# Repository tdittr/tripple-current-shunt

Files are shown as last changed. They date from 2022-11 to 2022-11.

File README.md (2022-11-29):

# Tripple Current Shunt

This is a small PCB project to measure current consumption and voltages in a multi battery camper van environment.

To do this it hosts three [INA219](https://www.ti.com/product/INA219) power monitors,
one [ADS1015](https://www.ti.com/product/ADS1015) four channel ADC to measure ground offsets,
one [MCP9808](https://www.microchip.com/en-us/product/MCP9808) temperature sensor and
a [M24C02](https://www.st.com/en/memories/m24c02-r.html) EEPROM to store calibration data.

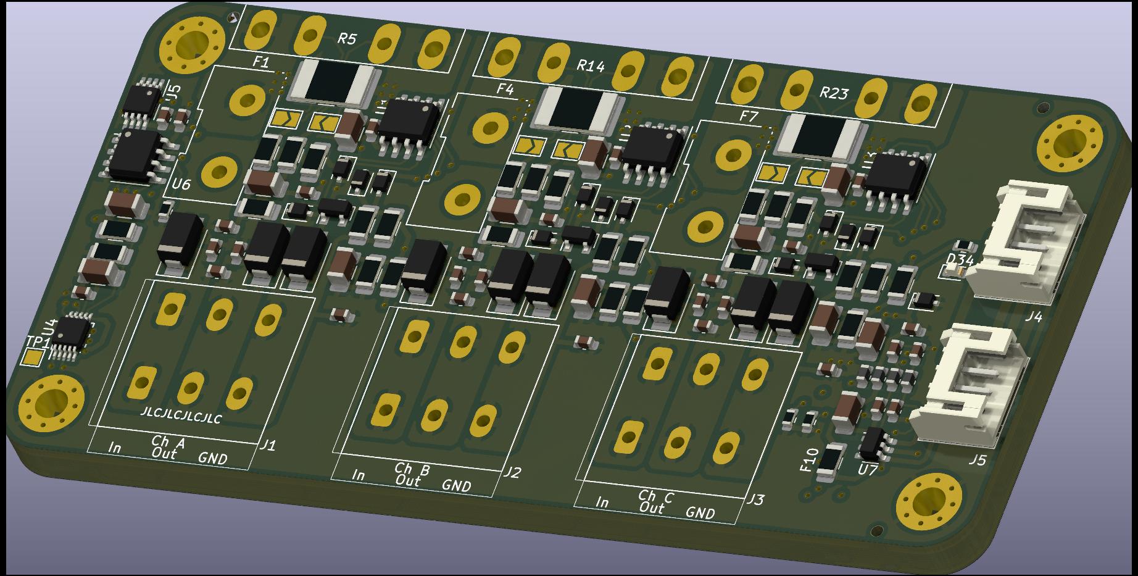
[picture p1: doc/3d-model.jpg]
3D Model of the board


## Interfaces

The board has three different interfaces. A [I2C](#i2c) digital interface for reading the measurements.
Three [Current Inputs](#current-input)
to measure the current flows into and out of the batteries. Three [Voltage Inputs](#voltage-input) to measure the ground
offset of the batteries.

### I2C

The I2C interface is wired to two JST-PH connectors with a pin-out compatible
to [Adafruits Stemma](https://learn.adafruit.com/introducing-adafruit-stemma-qt/technical-specs) connection. The
footprint also fits the connector and pin-out
of [Seedstudios Grove System](https://wiki.seeedstudio.com/Grove_System/#grove-i2c). The two connectors are wired in
parallel to allow for daisy-chaining. The power is also supplied via this connector (from rev2 onwards).

**Note on using Grove Connectors:** The 90 degree version of the grove connector seem to count their pins from right to
left - so inverse to how JST counts their pins. To use the Grove connectors you can either mount them on the backside of
the board or use the upright connectors with the clip facing to the edge of the board.

#### I2C Addresses

The six I2C slaves on the board are configured to follow a schema where the lowest two bits of the address are defined
per board. This allows usage of up to four boards with a total of 12 channels on a single bus. The individual addresses
are listed below. *xx* marks the bits set via jumpers (see screenshot below).

| Device | Address Pattern | Board 0 | Board 1 | Board 2 | Board 3 |
|---|---|---|---|---|---|
| MCP9808 | 0b001_10*xx* | 0x18 | 0x19 | 0x1a | 0x1b |
| INA219 Ch A | 0b100_00*xx* | 0x40 | 0x41 | 0x42 | 0x43 |
| INA219 Ch B | 0b100_01*xx* | 0x44 | 0x45 | 0x46 | 0x47 |
| ADS1015 | 0b100_10*xx* | 0x48 | 0x49 | 0x4a | 0x4b |
| INA219 Ch C | 0b100_11*xx* | 0x4c | 0x4d | 0x4e | 0x4f |
| M24C02 | 0b101_00*xx* | 0x50 | 0x51 | 0x52 | 0x53 |

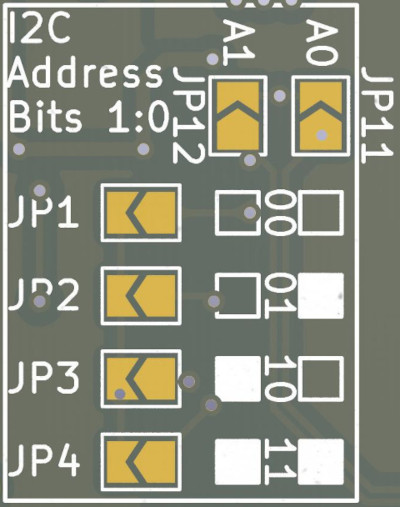
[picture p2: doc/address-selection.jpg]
Address selection jumpers screenshot
|                                                                                                                                      |
|--------------------------------------------------------------------------------------------------------------------------------------------------------------------------------------------------------|
| There should always be one of JP1, JP2, JP3 or JP4 closed. Then close JP11 or JP12 when the matching box is filled. To select for example the address *10* for the board you would close JP3 and JP12. |

### Current Input

The current inputs are connected inline between the batteries and the consumers. They can be connected using
either [Wago 2604-1103 terminal blocks](https://www.wago.com/global/pcb-terminal-blocks-and-pluggable-connectors/pcb-terminal-block/p/2604-1103)
or a single row terminal block with 5mm pin spacing.

The board offers the option to place a [miniOTO fuse holder](https://imaxx.nl/product/minioto-holder-h7810/) in line to
protect the board and connections.

The current is then converted to a voltage using a current shunt. The different options for this are described
in ["Choosing a Shunt Resistor"](#choosing-a-shunt-resistor).

### Voltage Input

To measure the voltage offset between the board ground and the battery ground the connector used for
the [Current Input](#current-input) offers an extra connection. The input can tolerate a maximum voltage of ±20V but can
only measure about a ±5V offset. This can easily be adapted to other needs,
see [Adapting Voltage Dividers](#adapting-voltage-dividers).

## Design considerations

The board is designed to be easily adaptable to different situations. The easiest adaptions are to just leave parts out:

* Remove the fuse holders (e.g. because you already have a fuse box), and bridge that footprint
* Remove the temperature sensor and/or EEPROM to save cost
* Remove the EMI filter by not populating the capacitors and bridging the ferrite-beads

For the more complex considerations see below:

### Choosing a Shunt Resistor

**1. Choosing a footprint:** The board offers four different footprints for the shunt resistors:

* Single-Inline 4-pin through-hole
  for [Isabellenhütte PBV](https://www.isabellenhuette.de/fileadmin/user_upload/PBV.PDF) resistors
* SMD 2512 resistors
* SMD 1206 resistors
* Off-Board Shunt like [Vishay RTOP](https://www.vishay.com/product/50045/)

When using any other resistor footprint then the Single-Inline one the two jumpers next to the resistor footprints needs
to be closed. This connects the voltage sense terminals to the current terminals.

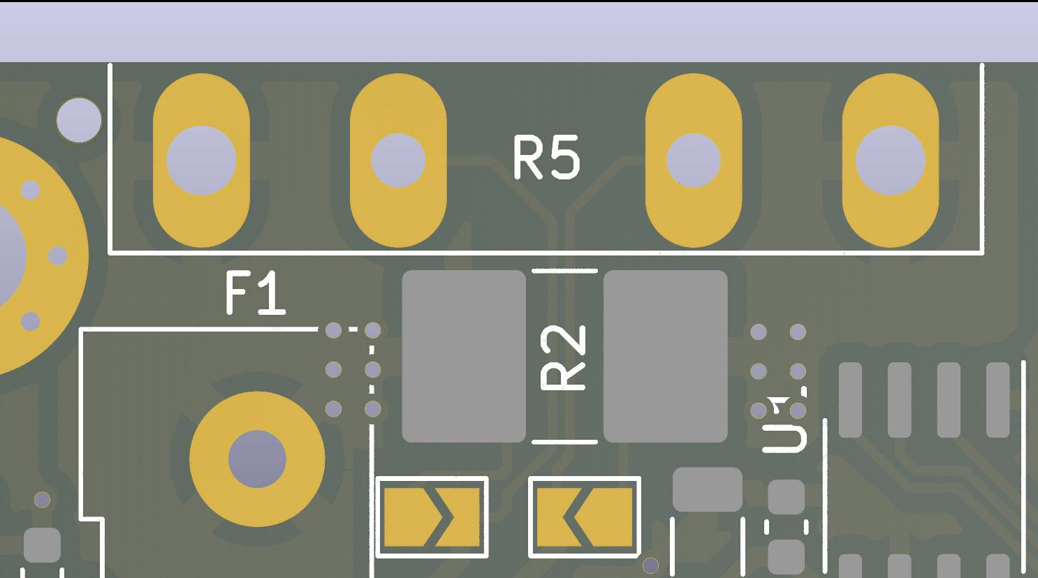
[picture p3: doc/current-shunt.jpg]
Shunt resistor footprints and jumpers


The screenshot shows the resistor footprints for channel A. R5 is for the *Single-Inline 4-pin through-hole* and R2 for
either SMD 2512 or SMD 1206. To use an external shunt do not populate any of the two. If you want to use any shunt that
is not the Single-Inline 4-pin close the two jumpers below R2.

**2. Check maximum values:** Calculate the maximum resistor value for a given current and power rating:

$R \leq \frac{P}{I^2}$

**3. Check voltage over shunt:** The INA219 can work with up to 26V but can measure a either ±40mV, ±80mV, ±160mV or
±320mV of shunt voltage. Using a lower shunt voltage will give a lower power loss on the shunt while aiming for a higher
shunt voltage increases signal-to-noise ratio.
You can calculate the voltage over the shunt by $U_{shunt}=R_{shunt} \cdot I$.

**Note:** Check whether the trace width is sufficient for your current. You can add extra solder and copper to the
traces on the bottom side to improve the current capabilities.

### Adapting Voltage Dividers

The voltage dividers for the ground offset are set to allow for ±5V input. This is achieved by building a voltage
divider between the input voltage and 5V. The output voltage can then be calculated by:

$U_{out} = \frac{5V + U_{in}}{2}$

There are however footprints to form a voltage divider between the input and ground. So it could be used to measure
another bus voltage.

**Note:** When adapting this take care to not overload the clamping diodes or the resistors in the voltage divider.

### Adapting Low Pass Filters

The current and voltage inputs host capacitors to form RC low-pass filters. The calculations for these can be found in
the schematic.

# License

Licensed under the CERN Open Hardware Licence Version 2 - Permissive.
Unless you explicitly state otherwise, any contribution intentionally submitted by you, shall be licensed as above,
without any additional terms or conditions.

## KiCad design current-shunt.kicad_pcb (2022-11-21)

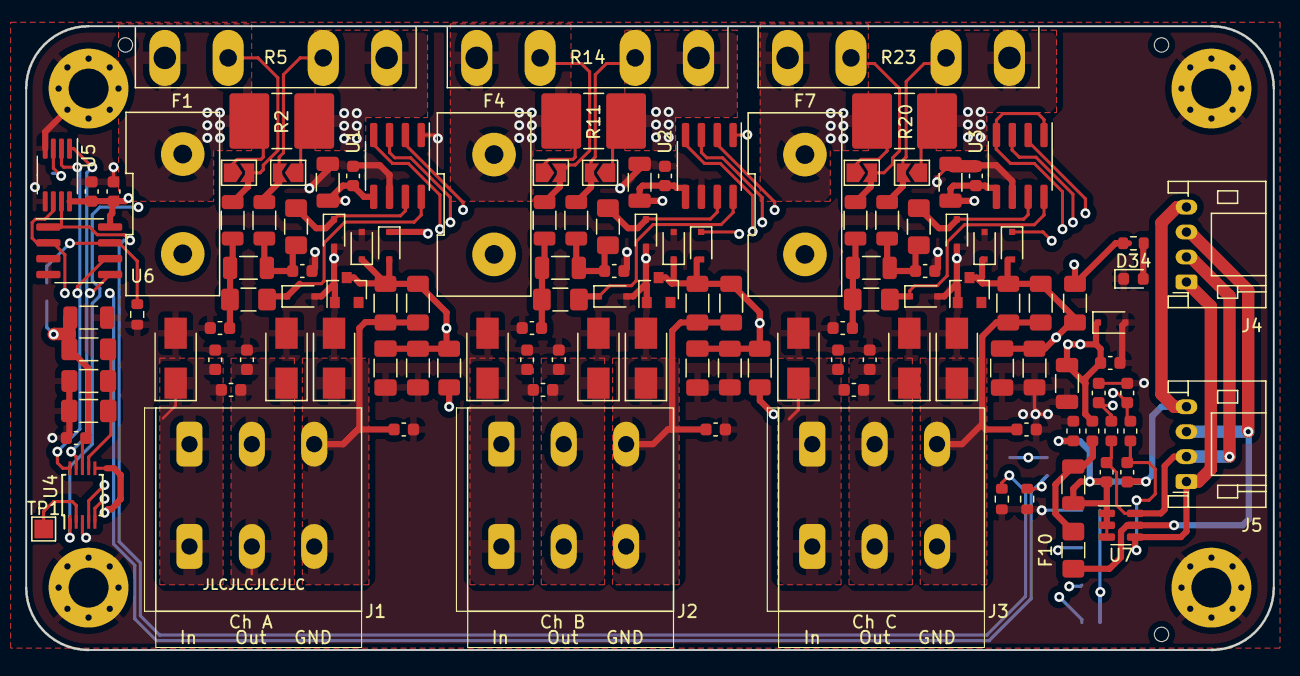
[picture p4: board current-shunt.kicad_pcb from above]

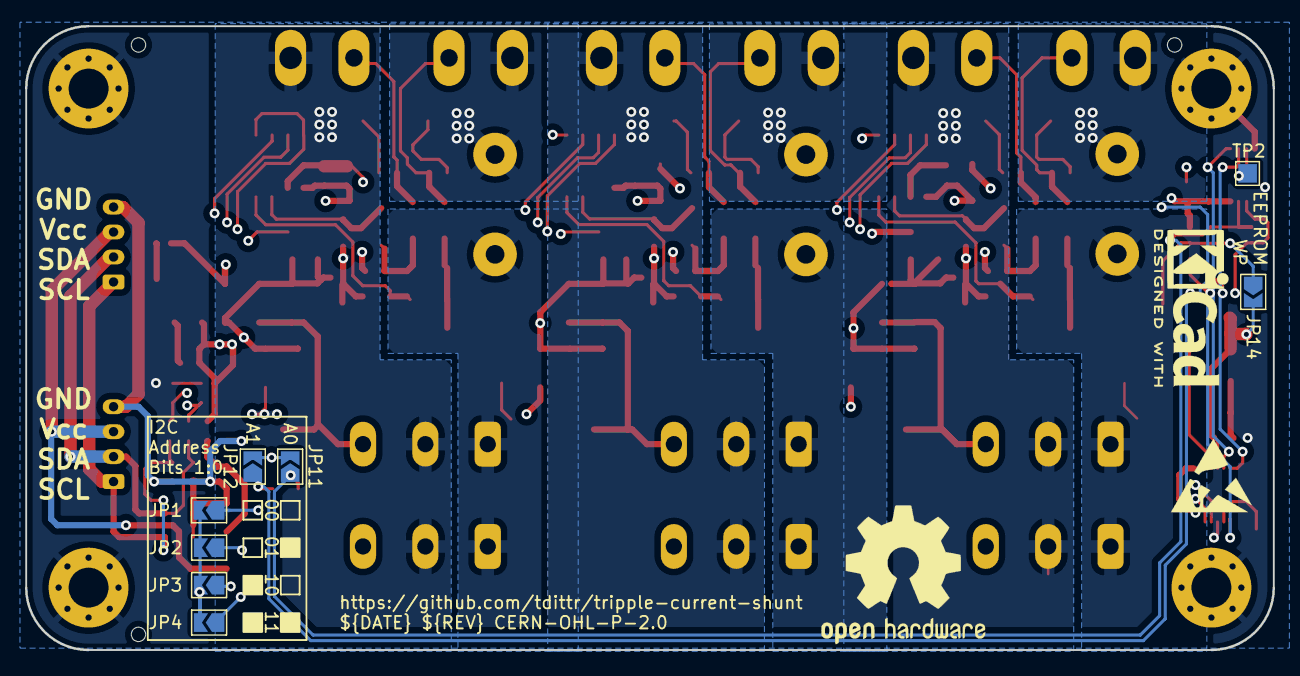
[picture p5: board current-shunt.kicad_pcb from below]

Board: 4 copper layers, 100.0 x 50.0 mm, 146 parts (11 on the bottom side), 50 nets.

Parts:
C1, C11, C21, C32, C37, C40: 10uF; C_1206_3216Metric
C2, C9, C10, C12, C19, C20, C22, C29, C30, C33, C34, C35, C36: 100nF; C_0603_1608Metric
C3, C4, C5, C6, C13, C14, C15, C16, C23, C24, C25, C26: 10nF; C_0603_1608Metric
C7, C17, C27, C31: 330nF; C_1206_3216Metric_Pad1.33x1.80mm_HandSolder
C8, C18, C28: 1uF; C_1206_3216Metric
C38, C39, C41, C42: 33pF; C_0603_1608Metric
D4, D5, D6, D15, D16, D17, D26, D27, D28: SMAJ20CA; D_SMA
D7, D8, D9, D10, D18, D19, D20, D21, D29, D30, D31, D32, D35: PMEG4010BEA; D_SOD-323F
D11, D22, D33: BZX84C 4V7; D_SOT-23_ANK
D34: LED; LED_0603_1608Metric
F1, F4, F7: Fuse; iMaXX-H7810
F2, F3, F5, F6, F8, F9, F10: 1206L016WR; Fuse_1206_3216Metric_Pad1.42x1.75mm_HandSolder
FB1, FB2, FB3, FB4: FerriteBead; L_0603_1608Metric
H1, H2, H3, H4: MountingHole_Pad; MountingHole_3.2mm_M3_Pad_Via
J1, J2, J3: Screw_Terminal_01x03; Wago_2604-1103
J4, J5: Conn_01x04; JST_PH_S4B-PH-K_1x04_P2.00mm_Horizontal
JP1, JP2, JP3, JP4, JP5, JP6, JP7, JP8, JP9, JP10, JP11, JP12, JP14: SolderJumper_2_Open; SolderJumper-2_P1.3mm_Open_TrianglePad1.0x1.5mm
LOGO1: Logo_Open_Hardware_Small; OSHW-Logo2_14.6x12mm_SilkScreen
LOGO2: SYM_ESD_Small; ESD-Logo_6.6x6mm_SilkScreen
LOGO3: SYM_Arrow45_XLarge; KiCad-Logo2_5mm_SilkScreen
R2, R11, R20: R; R_2816_7142Metric_Pad3.20x4.45mm_HandSolder
R3, R4, R12, R13, R21, R22: 2k; R_1206_3216Metric_Pad1.30x1.75mm_HandSolder
R5, R14, R23: R_Shunt; R_Shunt_Isabellenhuette_PBV
R6, R7, R15, R16, R24, R25: 10R; R_1206_3216Metric
R8, R17, R26, R28, R29: 1k; R_1206_3216Metric_Pad1.30x1.75mm_HandSolder
R9, R18, R27: DNP; R_1206_3216Metric_Pad1.30x1.75mm_HandSolder
R30, R31, R33: 10K; R_0603_1608Metric
R34: 1K5; R_0603_1608Metric
TP1, TP2: TestPoint; TestPoint_Pad_1.5x1.5mm
U1, U2, U3: INA219AxD; SOIC-8_3.9x4.9mm_P1.27mm
U4: ADS1015IDGS; TSSOP-10_3x3mm_P0.5mm
U5: MCP9804_MSOP; MSOP-8_3x3mm_P0.65mm
U6: M24C02-WMN; SOIC-8_3.9x4.9mm_P1.27mm
U7: SRV05-4; SOT-23-6

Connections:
+5V: C1.1, C2.1, C11.1, C12.1, C21.1, C22.1, C32.1, C33.1, C34.1, C35.1, C36.1, C37.1, D7.1 (K), D18.1 (K), D29.1 (K), D35.1 (K), FB1.1, JP2.1 (A), JP11.2 (B), JP12.2 (B), JP14.2 (B), R8.1, R17.1, R26.1, R28.1, R34.1, U1.5 (VS), U2.1 (A1), U2.5 (VS), U3.5 (VS), U4.8 (VDD), U5.8 (VDD), U6.8 (VCC)
/SCL: C39.1, FB3.1, JP4.1 (A), U1.4 (SCL), U2.4 (SCL), U3.1 (A1), U3.4 (SCL), U4.10 (SCL), U5.2 (SCL), U6.6 (SCL)
/SDA: C38.1, FB2.1, JP3.1 (A), U1.3 (SDA), U2.3 (SDA), U3.3 (SDA), U4.9 (SDA), U5.1 (SDA), U6.5 (SDA)
/gnd-level/A0: JP1.2 (B), JP2.2 (B), JP3.2 (B), JP4.2 (B), U1.2 (A0), U2.2 (A0), U3.2 (A0), U4.1 (ADDR)
/gnd-level/ALERT: TP1.1, U4.2 (ALERT/RDY)
/gnd-level/GND-A: C7.1, D7.2 (A), D8.1 (K), D11.1 (K), R3.1, R4.1, R8.2, R9.1, U4.4 (AIN0)
/gnd-level/GND-B: C17.1, D18.2 (A), D19.1 (K), D22.1 (K), R12.1, R13.1, R17.2, R18.1, U4.5 (AIN1)
/gnd-level/GND-C: C27.1, D29.2 (A), D30.1 (K), D33.1 (K), R21.1, R22.1, R26.2, R27.1, U4.6 (AIN2)
/i2c-interface/GND_e: C40.2, C41.2, C42.2, FB4.2, J4.4, J5.4, U7.1 (IO1), U7.2 (VN), U7.3 (IO2)
/i2c-interface/SCL_e: C42.1, FB3.2, J4.1, J5.1, U7.4 (IO3)
/i2c-interface/SDA_e: C41.1, FB2.2, J4.2, J5.2, U7.6 (IO4)
/i2c-interface/Vcc_e: F10.2, J4.3, J5.3, U7.5 (VP)
/shunt-a/IN+: C3.1, C4.1, D5.1 (A1), F1.1, J1.1
/shunt-a/IN+F: F1.2, JP5.1 (A), R2.1, R5.1
/shunt-a/IN-: C4.2, C5.1, D6.1 (A1), J1.2, JP6.1 (A), R2.2, R5.4
/shunt-a/IN-GND: C6.1, D4.1 (A1), J1.3, R3.2, R4.2
/shunt-b/IN+: C13.1, C14.1, D16.1 (A1), F4.1, J2.1
/shunt-b/IN+F: F4.2, JP7.1 (A), R11.1, R14.1
/shunt-b/IN-: C14.2, C15.1, D17.1 (A1), J2.2, JP8.1 (A), R11.2, R14.4
/shunt-b/IN-GND: C16.1, D15.1 (A1), J2.3, R12.2, R13.2
/shunt-c/IN+: C23.1, C24.1, D27.1 (A1), F7.1, J3.1
/shunt-c/IN+F: F7.2, JP9.1 (A), R20.1, R23.1
/shunt-c/IN-: C24.2, C25.1, D28.1 (A1), J3.2, JP10.1 (A), R20.2, R23.4
/shunt-c/IN-GND: C26.1, D26.1 (A1), J3.3, R21.2, R22.2
/temperature-sensor-eeprom/A0: JP11.1 (A), R30.1, U5.7 (A0), U6.1 (E0)
/temperature-sensor-eeprom/A1: JP12.1 (A), R31.1, U5.6 (A1), U6.2 (E1)
/temperature-sensor-eeprom/ALERT: TP2.1, U5.3 (Alert)
GND: C1.2, C2.2, C3.2, C5.2, C6.2, C7.2, C9.2, C10.2, C11.2, C12.2, C13.2, C15.2, C16.2, C17.2, C19.2, C20.2, C21.2, C22.2, C23.2, C25.2, C26.2, C27.2, C29.2, C30.2, C31.2, C32.2, C33.2, C34.2, C35.2, C36.2, C37.2, C38.2, C39.2, D4.2 (A2), D5.2 (A2), D6.2 (A2), D8.2 (A), D9.2 (A), D10.2 (A), D11.2 (A), D15.2 (A2), D16.2 (A2), D17.2 (A2), D19.2 (A), D20.2 (A), D21.2 (A), D22.2 (A), D26.2 (A2), D27.2 (A2), D28.2 (A2), D30.2 (A), D31.2 (A), D32.2 (A), D33.2 (A), D34.1 (K), D35.2 (A), FB4.1, H1.1, H2.1, H3.1, H4.1, JP1.1 (A), R9.2, R18.2, R27.2, R29.2, R30.2, R31.2, R33.2, U1.1 (A1), U1.6 (GND), U2.6 (GND), U3.6 (GND), U4.3 (GND), U5.4 (GND), U5.5 (A2), U6.3 (E2), U6.4 (VSS)
unnamed: C8.2, C9.1, F3.1, R7.2
unnamed: C8.1, C10.1, F2.1, R6.2
unnamed: C18.1, C20.1, F5.1, R15.2
unnamed: C18.2, C19.1, F6.1, R16.2
unnamed: C28.1, C30.1, F8.1, R24.2
unnamed: C28.2, C29.1, F9.1, R25.2
unnamed: C31.1, R28.2, R29.1, U4.7 (AIN3)
unnamed: C40.1, F10.1, FB1.2
unnamed: D9.1 (K), F2.2, U1.8 (IN+)
unnamed: D10.1 (K), F3.2, U1.7 (IN-)
unnamed: D20.1 (K), F5.2, U2.8 (IN+)
unnamed: D21.1 (K), F6.2, U2.7 (IN-)
unnamed: D31.1 (K), F8.2, U3.8 (IN+)
unnamed: D32.1 (K), F9.2, U3.7 (IN-)
unnamed: D34.2 (A), R34.2
unnamed: JP5.2 (B), R5.2, R6.1
unnamed: JP6.2 (B), R5.3, R7.1
unnamed: JP7.2 (B), R14.2, R15.1
unnamed: JP8.2 (B), R14.3, R16.1
unnamed: JP9.2 (B), R23.2, R24.1
unnamed: JP10.2 (B), R23.3, R25.1
unnamed: JP14.1 (A), R33.1, U6.7 (~WC)

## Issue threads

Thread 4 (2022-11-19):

I2C Connector Pin-Out

tdittr, 2022-11-19:
The pin-out of the I2C connectors seems to be mirrored to what Stemma/Grove expect. Needs checking and changing...

Closed 2022-11-21.

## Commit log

2022-10-25 Squash all the commits containing Wago footprint
    This should get rid of any content containing the
    copyrighted footprint even on the board. Not
    sure if this is really needed but I want to avoid
    any problems with licensing.
    This commit squashes all these commits:
    ---
    Initial commit
    ---
    Finish layout
    ----
    Add TVS for I2C interface
    ---
    Update component values and add clamping diode
    The input resistor for GND lvl measurement was above the
    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
    [current-shunt.kicad_pcb, current-shunt.kicad_sch, gnd-input.kicad_sch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]
2022-10-25 Add License to repo and board
    [current-shunt.kicad_pcb, current-shunt.kicad_sch]
2022-10-25 Add a lot of nice to haves
    * Jumpers to bridge isolation
    * I2C pullups with jumpers for input
    * Labels on input connectors
    * Geographic reference counts
    [current-shunt.kicad_pcb, current-shunt.kicad_sch, gnd-level.kicad_sch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]
2022-10-25 Cleanup custom footprints and symbols
    This makes the names more descriptive and gets rid of unused
    symbols.
    [current-shunt.kicad_pcb, current-shunt.kicad_sch, shunt.kicad_sch]
2022-10-25 Update iMaXX H7810 footprint
    Finally found a better datasheet with more measurements.
    [current-shunt.kicad_pcb, shunt.kicad_sch]
2022-10-25 Update sheetname to match new use
    [current-shunt.kicad_pcb, current-shunt.kicad_sch, temp-eeprom.kicad_sch]
2022-10-25 Add LCSC order numbers to more easily order at JLCPCB
    [current-shunt.kicad_pcb, current-shunt.kicad_sch, gnd-level.kicad_sch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]
2022-10-25 Remove PCB only parts from BOM
    [current-shunt.kicad_pcb, current-shunt.kicad_sch, i2c.kicad_sch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]
2022-10-25 Add JLCPCB rotation offsets
    [current-shunt.kicad_pcb, current-shunt.kicad_sch, gnd-level.kicad_sch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]
2022-10-25 Add JLCPCB tooling and marking
    [current-shunt.kicad_pcb]
2022-10-28 Add labels to board and update not available component
    [current-shunt.kicad_pcb, current-shunt.kicad_sch, shunt.kicad_sch]
2022-11-18 Shrink board and reduce features to reduce price
    * Shrink to 100mm x 50mm
    * Remove voltage regulator and use Stemma Power instead
    * Remove isolation (is easier to add outside when needed)
    * Remove reverse indicators to save space
    * Remove I2C pullups as they are no longer needed
    * Fix A2 of EEPROM and Temperature sensor to 0 to save space
    [current-shunt.kicad_pcb, current-shunt.kicad_sch, gnd-level.kicad_sch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]
2022-11-21 Improve I2C documentation
    * Add note about Grove Connector quirk
    * Add signal labels to board
    * Add full list of I2C addresses
    [current-shunt.kicad_pcb]
2022-11-21 Switch shunt footprint
    The 2816 footprint is big enough to also mount all the smaller
    resistors down to 1206 and allows munting the bigger 2816
    resistors.
    [current-shunt.kicad_pcb, current-shunt.kicad_sch, shunt.kicad_sch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]
2022-11-29 Update README.md
    Fix a wrong I2C address for the EEPROM

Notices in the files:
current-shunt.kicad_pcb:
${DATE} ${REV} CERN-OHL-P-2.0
